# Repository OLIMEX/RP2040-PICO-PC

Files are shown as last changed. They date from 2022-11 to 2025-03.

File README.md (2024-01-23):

# RP2040-PICO-PC
Board of peripherals for Raspberry Pi RP2040-PICO which adds:

- HDMI/DVI 
- Audio 
- Micro SD card 
- Li-po charger 
- UEXT
- USB-OTG 

Allows to create a small PC with monitor and keyboard.

The RP2040-PICO-PC design is Open-Source Hardware (OSHW).

## Licenses

* Hardware is released under CERN Open Hardware Licence Version 2 - Strongly Reciprocal, all silkscreen credits to Olimex should remain;
* Software is released under GPL3 Licensee
* Documentation is released under CC BY-SA 4.0

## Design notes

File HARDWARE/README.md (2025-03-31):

RP2040-PICO-PC HARDWARE

This folder conaints design source files for each major hardware revisions.

There are also PDF exports of the schematic and BOM exports available.

The designs are made with KiCAD. Below you can find revision changes:

====

- Hardware revision D

1. Con2 changed to qwst1 and pinout changed!
2. Imropoved the pads and the soldering of all bigger components. They should now be more sturdy.

====

- Hardware revision C

1. Added diode D1 at the HDMI connector. R6 changed to 27k.
2. I2C1 fixed. SCL and SDA were swapped at the processor (3.3V).
3. Added needed resistors and capacitors and ferrite beads to SD_Card.
4. Board size increased.

====

- Hardware revision B

Initial release.

====

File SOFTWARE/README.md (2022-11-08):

Software examples for Olimex RP2040-PICO-PC and Raspberry Pi Pico

Folder "no-OS-FatFS-SD-SPI-RPi-Pico" contains SD card example, the project was adapted for RP2040-PICO-PC using this one:

https://github.com/carlk3/no-OS-FatFS-SD-SPI-RPi-Pico

Folder "PicoDVI" contains DVI example, the project is made after this one:

https://github.com/Wren6991/PicoDVI

Folder "pico-pwm-audio" contains audio examle, the project is based on this one:

https://github.com/rgrosset/pico-pwm-audio

Folder "Prebuilt-UF2" contains prebuilt binaries for each of the three projects.

The environment to build the projects was configured accordind to the getting-started-with-pico.pdf guide:

https://datasheets.raspberrypi.com/pico/getting-started-with-pico.pdf

If you don't want to bother with building just use the prebuilt UF2 files, connect the Raspberry Pi Pico to your computer using a micro-USB cable, making sure that you hold down the BOOTSEL button to force it into USB Mass Storage Mode. The board should automatically appear as a external drive. You can now drag-and-drop the UF2 binary onto the external drive.

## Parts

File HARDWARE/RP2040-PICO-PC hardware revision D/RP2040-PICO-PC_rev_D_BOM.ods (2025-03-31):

Qty | Designation | Package | Designator
2 | 100OHM/0402 | R_0402_5MIL_DWS | R17,R20
2 | 220OHM/0402 | R_0402_5MIL_DWS | R18,R19
9 | 270OHM/0402 | R_0402_5MIL_DWS | R7,R8,R9,R10,R11,R12,R13,R14,R25
1 | 1.5K/0402 | R_0402_5MIL_DWS | R1
2 | 1.8K/0603 | R_0603_5MIL_DWS | R16,R21
1 | 2K/0402 | R_0402_5MIL_DWS | R4
6 | 2.2K/0402 | R_0402_5MIL_DWS | R2,R3,R15,R26,R27,R28
2 | 10K/0402 | R_0402_5MIL_DWS | R24,R29
1 | 100K/0402 | R_0402_5MIL_DWS | R5
1 | 27K/0402 | R_0402_5MIL_DWS | R6
1 | RMAT(4x0603)100K/5% | RA1206_(4X0603)_4B8_xx | RM1
3 | 100nF/10V/20%/X5R/0402 | C_0402_5MIL_DWS | C4,C5,C6
1 | 1uF/10V/10%/X5R/0603 | C_0603_5MIL_DWS | C2
1 | 10uF/6.3V/0603 | C_0603_5MIL_DWS | C1
2 | 47uF/6.3V/20%/X5R/0805 | C_0805_5MIL_DWS | C7,C3
1 | 600OHM/2A/ UPZ2012E-601-2R0TF/0805 | L_0805_5MIL_DWS | L1
1 | 1N5819(S4 SOD-123) | SOD-123_1C-2A_KA | D1
1 | LED/RED/300 mCd/0603 | LED_0603_KA | LED1
2 | BSS138 | SOT23 | FET2,FET3
1 | WPM2015-3/TR | SOT23 | FET1
1 | BL4054B-42TPRN | SOT-23-5 | U1
1 | 74LVC125APW | 74LVC125A(TSSOP14-14_-SOT402-1) | U3
1 | 2X(PN1X20(F-D-1X20-LF)) | RP_Pico2040 | RP2040_PLATFORM1
1 | TFC-WPAPR-08-LF | TFC-WPAPR-08 | MICRO_SD1
1 | DW02S | LIPO_BAT_VERTICAL_DW02S | BAT_CON1
1 | BH10S(B-D-02x5-LF) | BH10S | UEXT1
1 | SH1.0-4P-180D | BM04B-SRSS-TB | QWST1
1 | HDMI-SWM-19 | HDMI-SWM-19_Paste | HDMI1
1 | MISB-SWMM-5B-LF | USB-MICRO_MISB-SWMM-5B_LF_Past | USB1
1 | 3.5mm/PJ-W47S-05D2-LF | PJ-W47S-05D2-LF_5PIN_V2_LongerPads | AUDIO_JACK_1
1 | HN1x3 | HN1x3 | DBG1
1 | TACTILE/YTS-A016-X | YTS-A016-X | RST1
1 | FSMD035-1206 (NANOSMDC035F-2) | FUSE-1206 | FUSE1
1 | open | SJ_1_SMALLER | 5V_ENABLE1
2 | NA/0402 | R_0402_5MIL_DWS | R22,R23

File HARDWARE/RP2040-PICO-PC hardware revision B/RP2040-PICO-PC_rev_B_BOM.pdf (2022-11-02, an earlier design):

RP2040-PICO-PC_rev_B | 04/26/2021
Qty | Designation | Package | Designator
2 | SMD RES 0402 100 OHM 5% | R_0402_5MIL_DWS | R17,R20
2 | SMD RES 0402 220 OHM 5% | R_0402_5MIL_DWS | R18,R19
9 | SMD RES 0402 270 OHM 5% | R_0402_5MIL_DWS | R7,R8,R9,R10,R11, R12,R13,R14,R25
1 | SMD RES 0402 1.5 K 5% | R_0402_5MIL_DWS | R1
2 | SMD RES 0603 1.8 K 5% | R_0603_5MIL_DWS | R16,R21
1 | SMD RES 0402 2 K 5% | R_0402_5MIL_DWS | R4
7 | SMD RES 0402 2.2 K 5% | R_0402_5MIL_DWS | R2,R3,R6,R15, R26,R27,R28
1 | SMD RES 0402 10 K 5% | R_0402_5MIL_DWS | R24
1 | SMD RES 0402 100 K 5% | R_0402_5MIL_DWS | R5
2 | NA/0402 | R_0402_5MIL_DWS | R22,R23
1 | SMD CAP 0603 1 UF 10V X5R | C_0603_5MIL_DWS | C2
1 | SMD CAP 0603 10 UF 6.3V | C_0603_5MIL_DWS | C1
2 | SMD CAP 0805 47 UF 6.3V 20% | C_0805_5MIL_DWS | C3,C7
1 | SMD IC 74LVC125APW | 74LVC125A (TSSOP14-14_leads-4.4mm_body_width-SOT402-1) | U3
1 | BH10S(B-D-02x5-LF) | BH10S | UEXT1
1 | SMD IC BL4054B-42TPRN | SOT-23-5 | U1
2 | SMD TR BSS138 | SOT23 | FET2,FET3
1 | CI0104P1VK0(PH-4A) | CL0104PV1K0 | CON2
1 | DW02S | LIPO_BAT_ VERTICAL_DW02S | BAT_CON1
1 | SMD FUSE FSMD035 | FUSE-1206 | FUSE1
1 | HDMI-SWM-19 | HDMI-SWM-19-TEST | HDMI1
1 | SMD CON TFC-WPAPR-08 | TFC-WPAPR-08 | MICRO_SD1
1 | HN1x3 | HN1x3 | DBG1
1 | PJ-W47S-05D2-LF_V2 | PJ-W47S-05D2-LF_5PIN_V2 | AUDIO_JACK_1
1 | HN 1X40 | HN 1X40 | U2
1 | SMD LED 0603 RED 300 mCd | LED_0603_KA | LED1
1 | TSW34-W16PR-220-LF/SIDE | SIDE_WTCM-TR(3x4) | RST1
1 | SMD CON MISB-SWMM-5B-LF | USB-MINI | USB1
1 | SMD TR WPM2015-3/TR | SOT23 | FET1

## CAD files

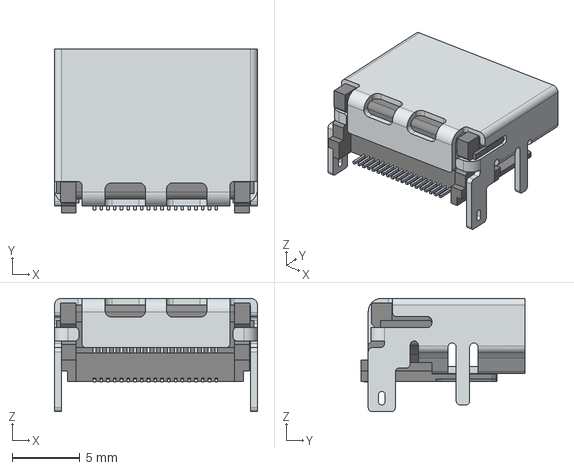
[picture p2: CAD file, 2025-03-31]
HARDWARE/RP2040-PICO-PC hardware revision D/3d/HDMI_19POS_SMD_Wurth_Electronic-685119134923.stp
15.0 x 12.2 x 8.38 mm

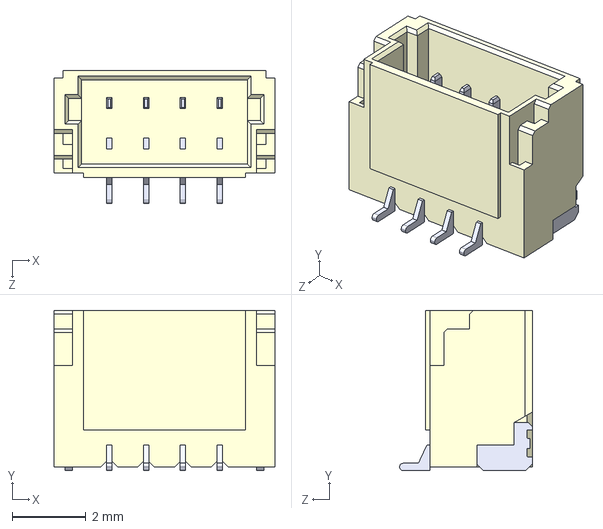
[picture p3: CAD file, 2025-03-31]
HARDWARE/RP2040-PICO-PC hardware revision D/3d/BM04B-SRSS-TB.STEP
6.00 x 4.35 x 3.60 mm

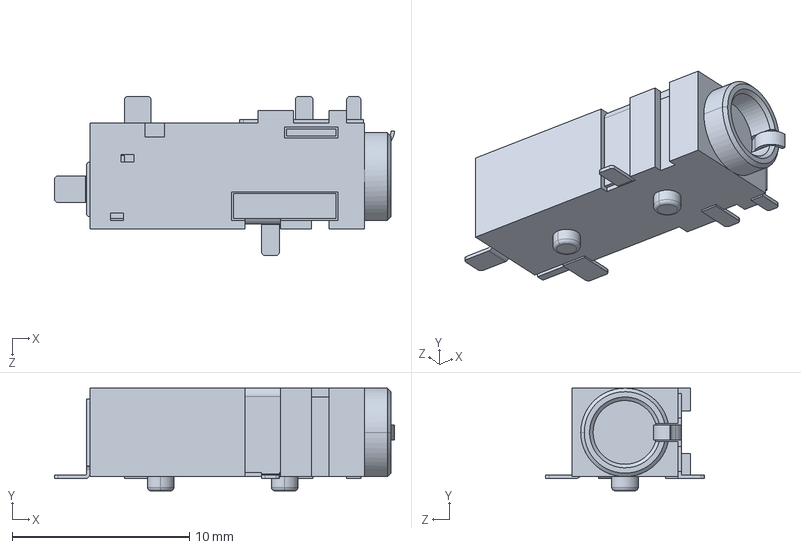
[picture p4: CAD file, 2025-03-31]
HARDWARE/RP2040-PICO-PC hardware revision D/3d/CUI_SJ-43515TS-SMT-TR.step
19.2 x 5.80 x 9.00 mm

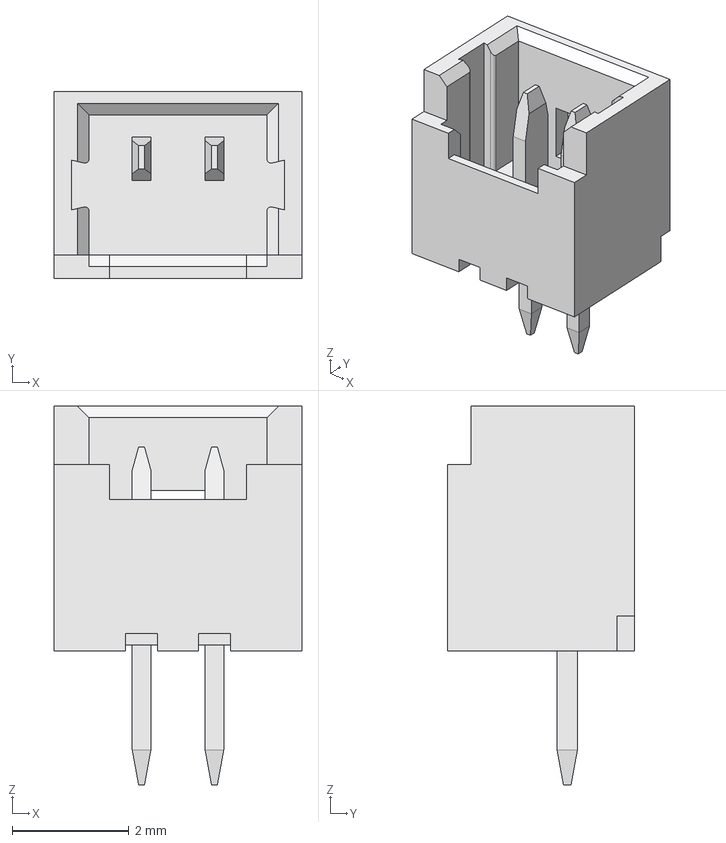
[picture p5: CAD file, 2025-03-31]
HARDWARE/RP2040-PICO-PC hardware revision D/3d/Molex_PicoBlade_530470210.step
4.25 x 3.20 x 6.50 mm

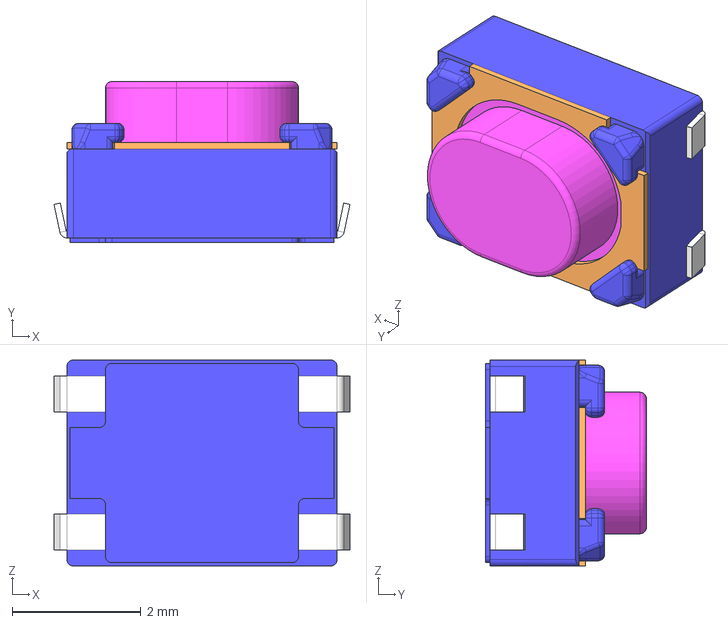
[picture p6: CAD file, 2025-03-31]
HARDWARE/RP2040-PICO-PC hardware revision D/3d/YTS-A016-X(SKRPABE010).stp
4.60 x 2.50 x 3.20 mm

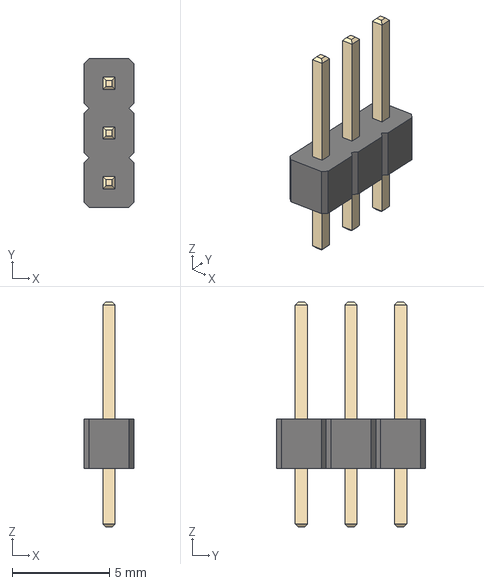
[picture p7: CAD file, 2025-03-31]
HARDWARE/RP2040-PICO-PC hardware revision D/3d/HN1x3-PinHeader_1x03_P2.54mm_Vertical.step
2.54 x 7.62 x 11.5 mm

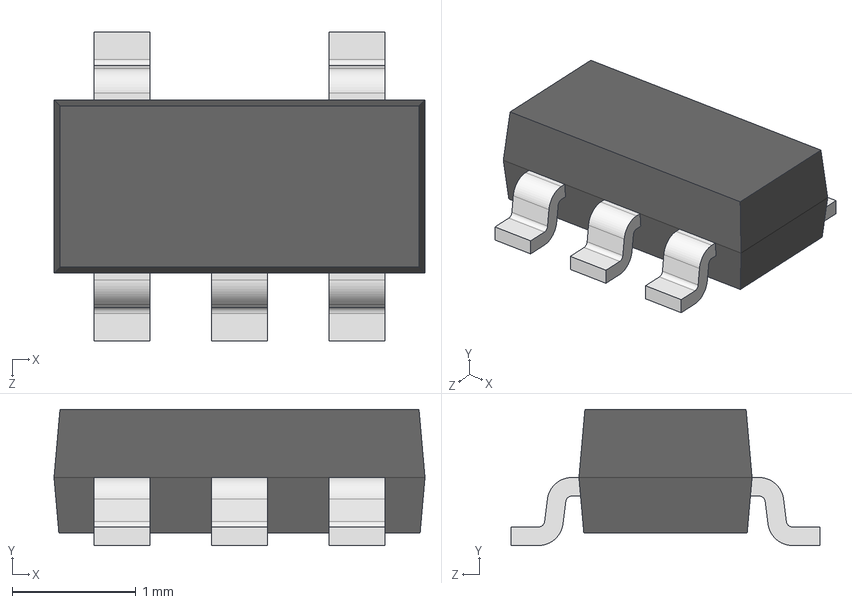
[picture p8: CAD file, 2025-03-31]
HARDWARE/RP2040-PICO-PC hardware revision D/3d/SOT-23-5.step
3.00 x 1.10 x 2.50 mm

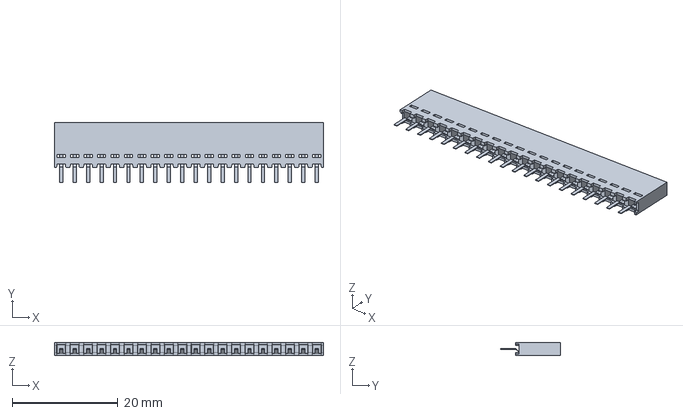
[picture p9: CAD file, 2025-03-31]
HARDWARE/RP2040-PICO-PC hardware revision D/3d/PN1x20-Molex_C-Grid_901471120_1x20_P2.54mm_Vertical.step
50.8 x 11.4 x 2.54 mm

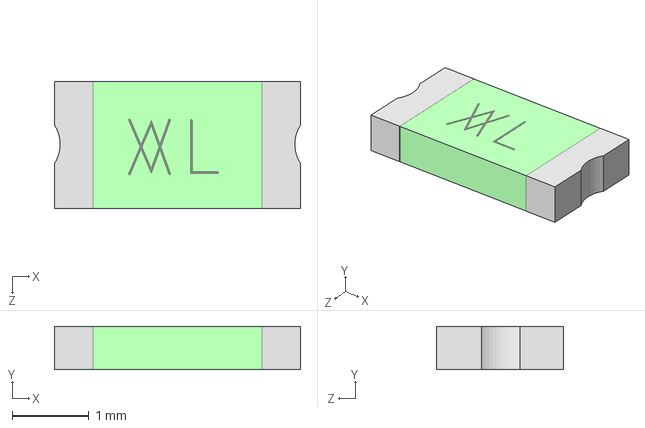
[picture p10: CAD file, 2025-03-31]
HARDWARE/RP2040-PICO-PC hardware revision D/3d/SMD075F.step
3.20 x 0.562 x 1.65 mm

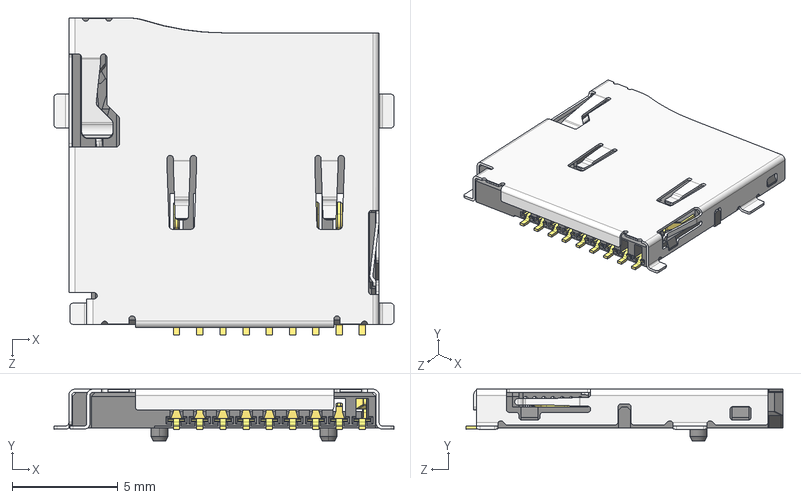
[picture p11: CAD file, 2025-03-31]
HARDWARE/RP2040-PICO-PC hardware revision D/3d/TFC-WPAPR-08---112J-TXAR-R_C_1-1.STEP
16.1 x 2.45 x 15.0 mm

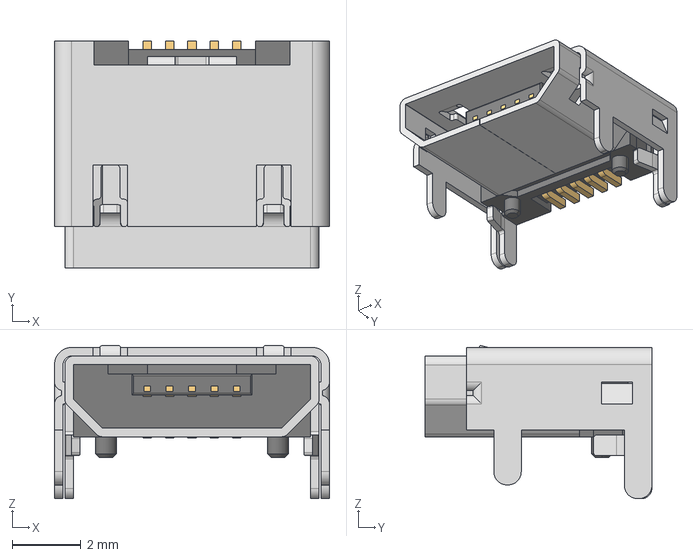
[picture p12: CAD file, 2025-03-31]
HARDWARE/RP2040-PICO-PC hardware revision D/3d/usb_micro_4p.stp
8.00 x 6.60 x 4.46 mm

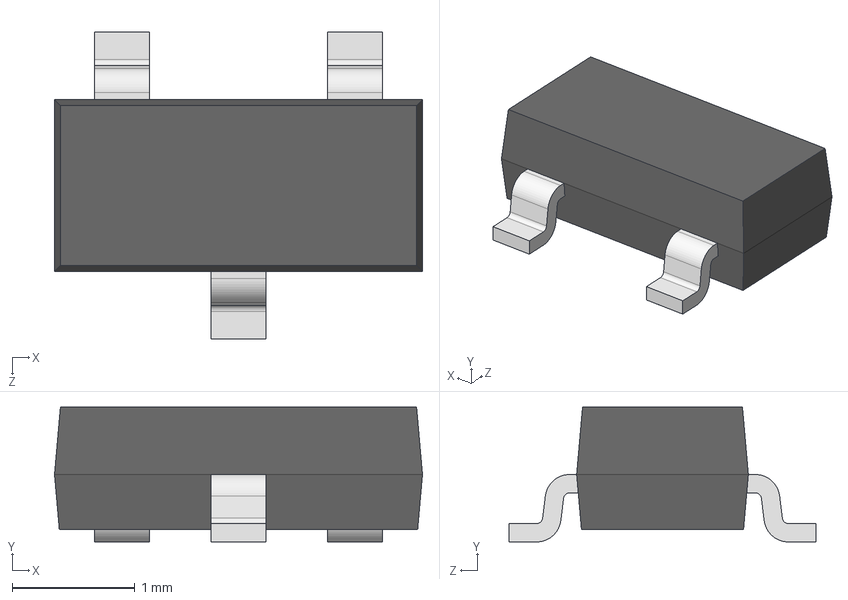
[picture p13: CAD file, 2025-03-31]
HARDWARE/RP2040-PICO-PC hardware revision D/3d/SOT-23.step
3.00 x 1.10 x 2.50 mm

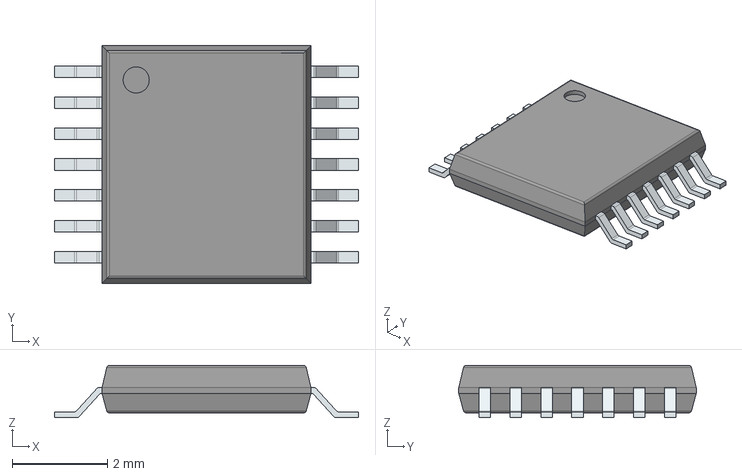
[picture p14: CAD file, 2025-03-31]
HARDWARE/RP2040-PICO-PC hardware revision D/3d/74LVC125APW,118.stp
6.40 x 5.00 x 1.10 mm
PinsArrayLR

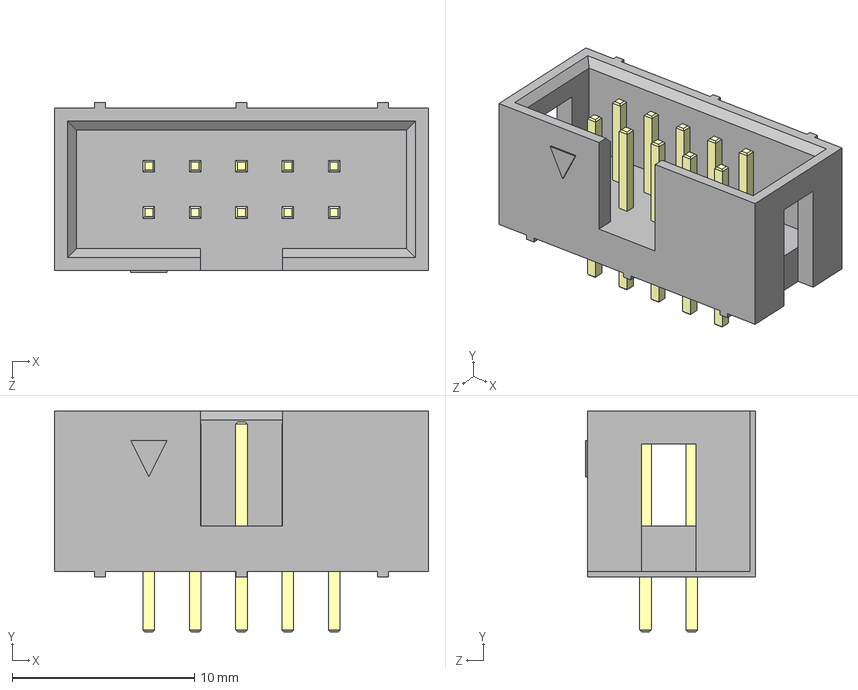
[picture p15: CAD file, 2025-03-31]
HARDWARE/RP2040-PICO-PC hardware revision D/3d/BH-10__64.step
20.5 x 12.1 x 9.30 mm

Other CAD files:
HARDWARE/RP2040-PICO-PC hardware revision D/3d/SOD123.step
HARDWARE/RP2040-PICO-PC hardware revision C/3d/CI0104P1VK0.STEP
HARDWARE/RP2040-PICO-PC hardware revision C/3d/SOD123.step

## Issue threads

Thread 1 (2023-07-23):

Use of PWM sound with DVI

ikjordan, 2023-07-23:
The supplied PicoDVI code uses PWM to generate the DVI clock on pins 12 and 13. The boards audio out is on pins 27 and 28.

Pin 28 and pin 12 are on the same PWM channel (6A), so it is not possible to configure different PWM clock frequencies for the two pins.
In effect this means that PWM stereo sound does not work with the supplied PicoDVI code.

A workaround is to generate the DVI clock via a very simple pio state machine. The PWM clock can then be configured for pin 28.

The PicoDVI library at:
https://github.com/ikjordan/PicoDVI
has been updated with these changes. I can raise a PR on this repo if you would like

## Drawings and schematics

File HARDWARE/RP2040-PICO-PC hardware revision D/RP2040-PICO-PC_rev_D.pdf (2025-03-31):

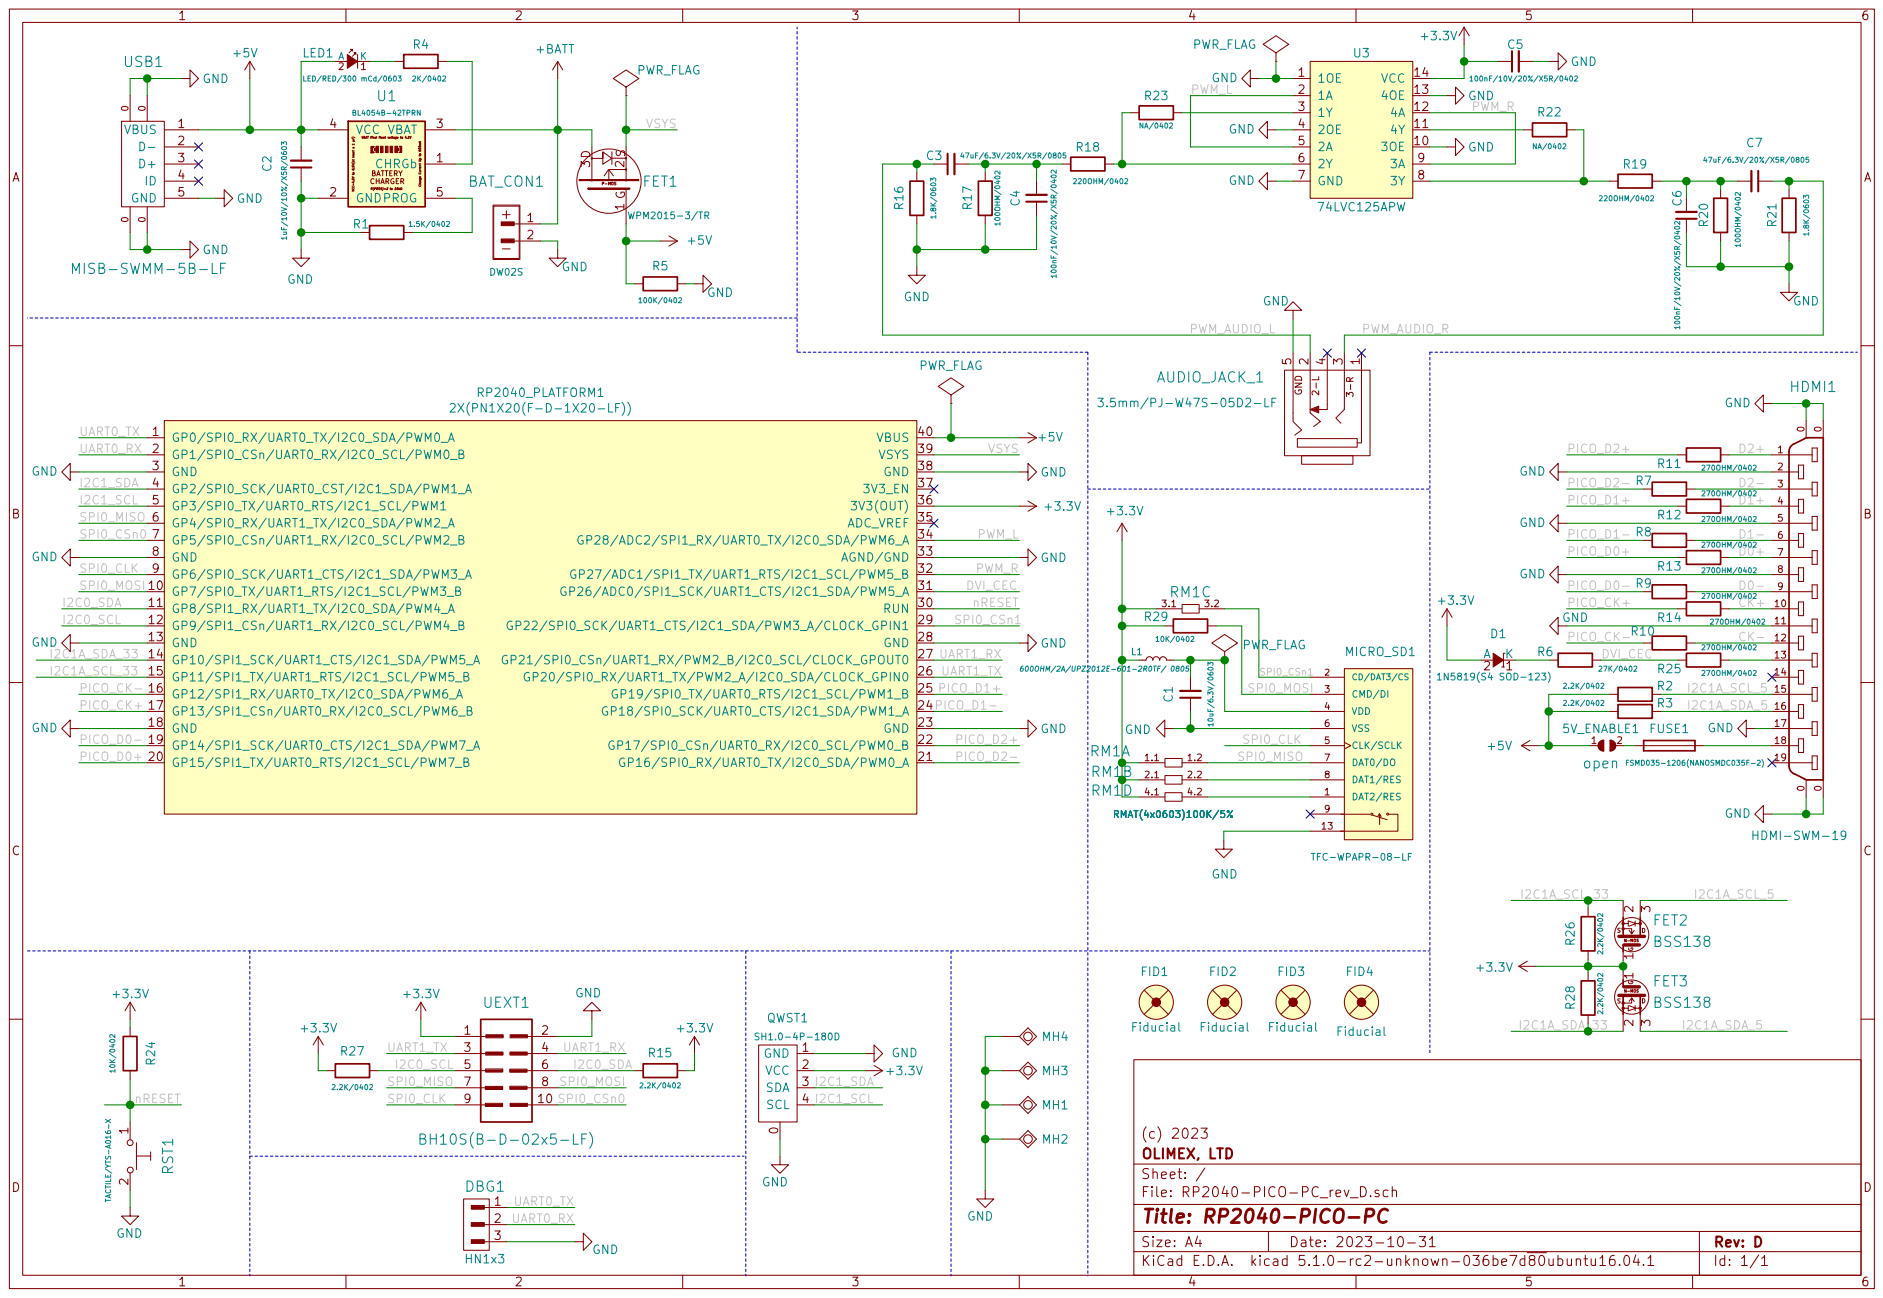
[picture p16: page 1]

LED/RED/300 mCd/0603 GND C2 1uF/10V/10%/X5R/0603 +5V

0 GND 1 VCC 2 SDA 3 SCL 4 QWST1

File: RP2040-PICO-PC_rev_D.sch Sheet: / OLIMEX, LTD

Id: 1/1 Title: RP2040-PICO-PC

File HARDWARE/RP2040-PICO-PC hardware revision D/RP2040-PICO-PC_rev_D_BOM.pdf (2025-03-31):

RP2040-PICO-PC_rev_D-BOM | 11/03/2023

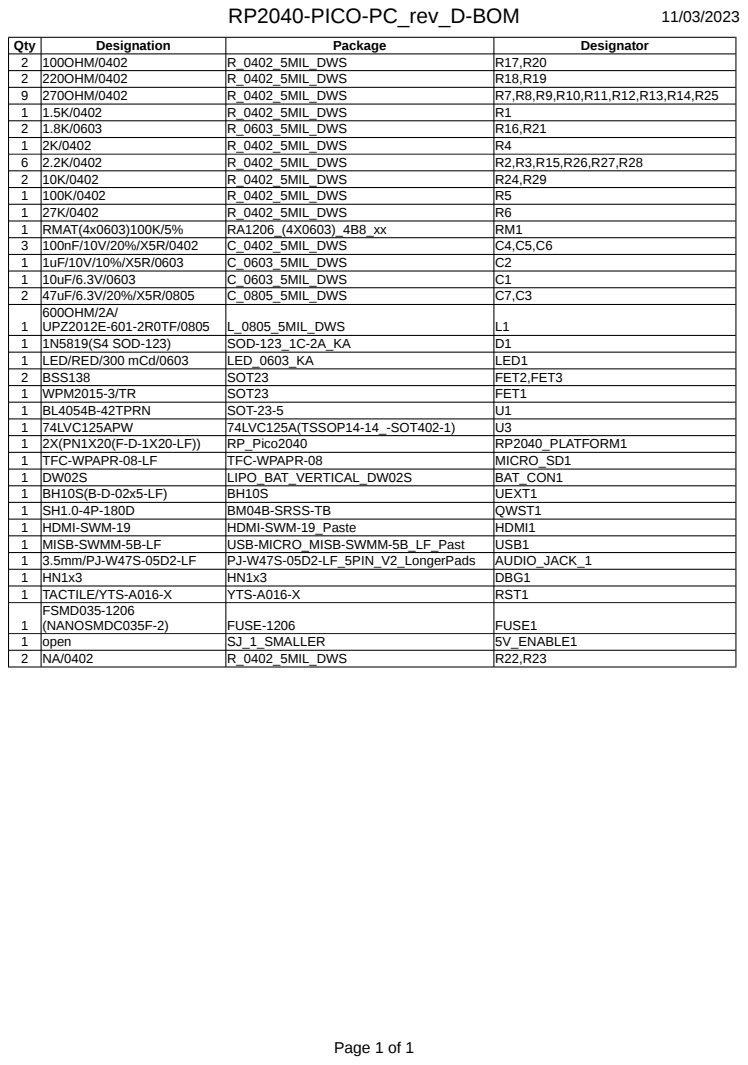
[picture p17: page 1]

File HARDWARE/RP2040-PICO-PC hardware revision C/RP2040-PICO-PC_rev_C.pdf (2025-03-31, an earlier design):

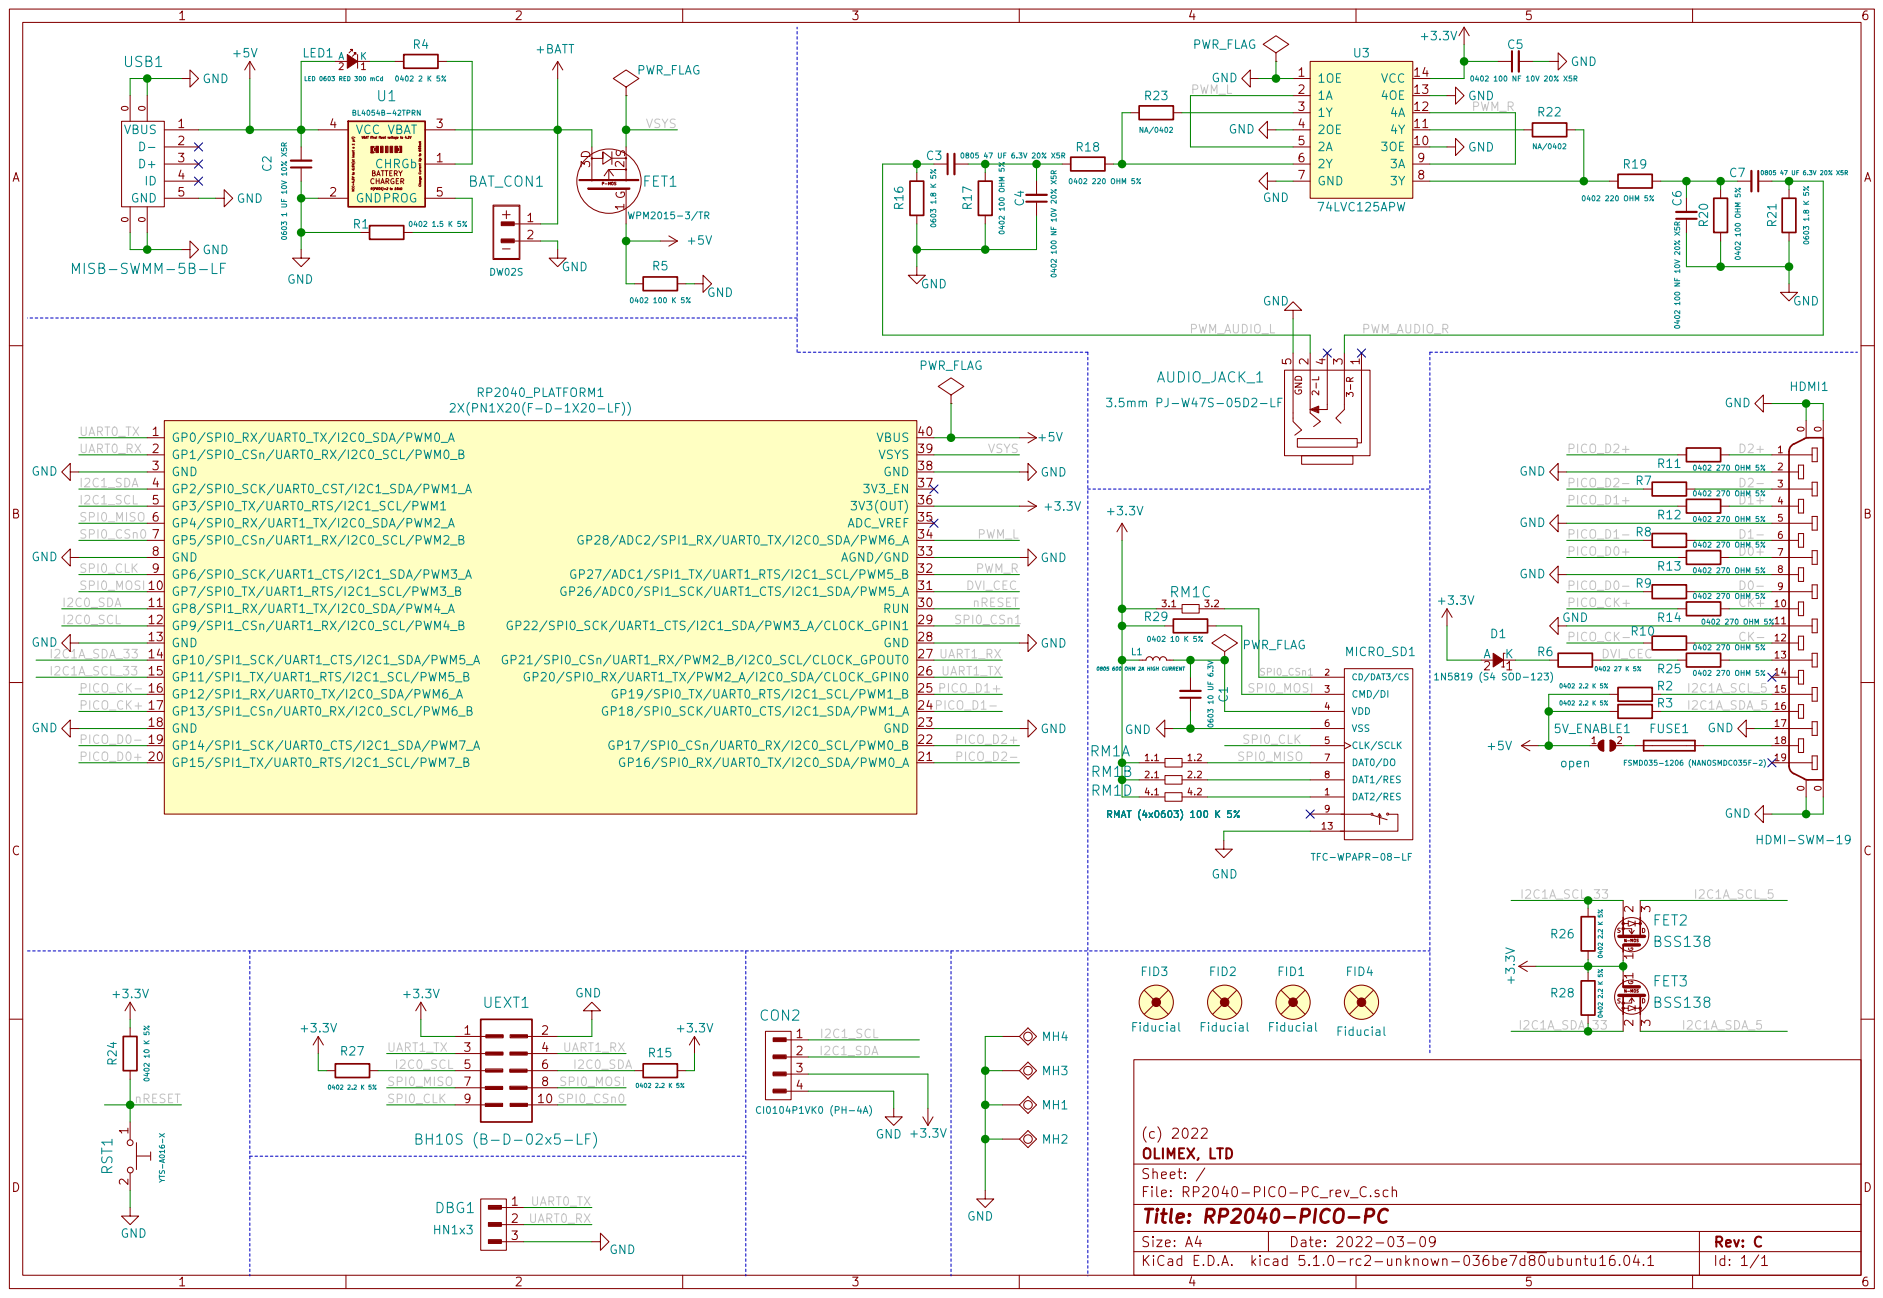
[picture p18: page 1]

LED 0603 RED 300 mCd GND C2 0603 1 UF 10V 10% X5R +5V

File: RP2040-PICO-PC_rev_C.sch Sheet: / OLIMEX, LTD

Id: 1/1 Title: RP2040-PICO-PC

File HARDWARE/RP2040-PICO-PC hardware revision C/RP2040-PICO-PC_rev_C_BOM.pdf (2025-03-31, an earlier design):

RP2040-PICO-PC_Rev_C_BOM | 03/10/2022

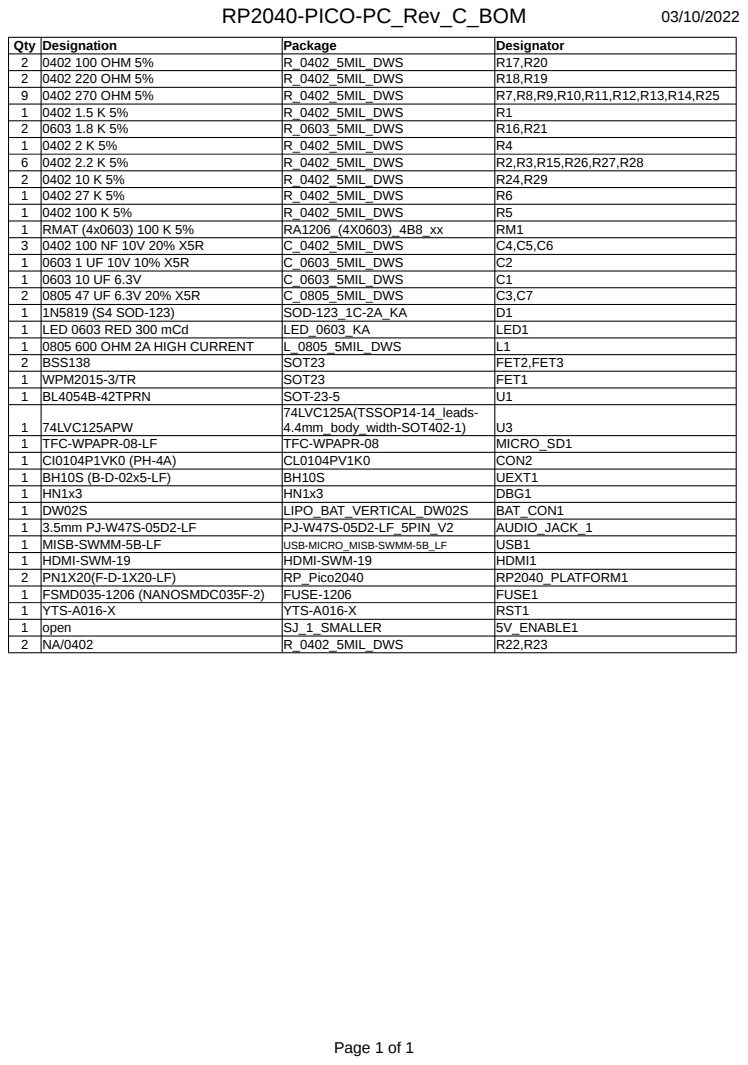
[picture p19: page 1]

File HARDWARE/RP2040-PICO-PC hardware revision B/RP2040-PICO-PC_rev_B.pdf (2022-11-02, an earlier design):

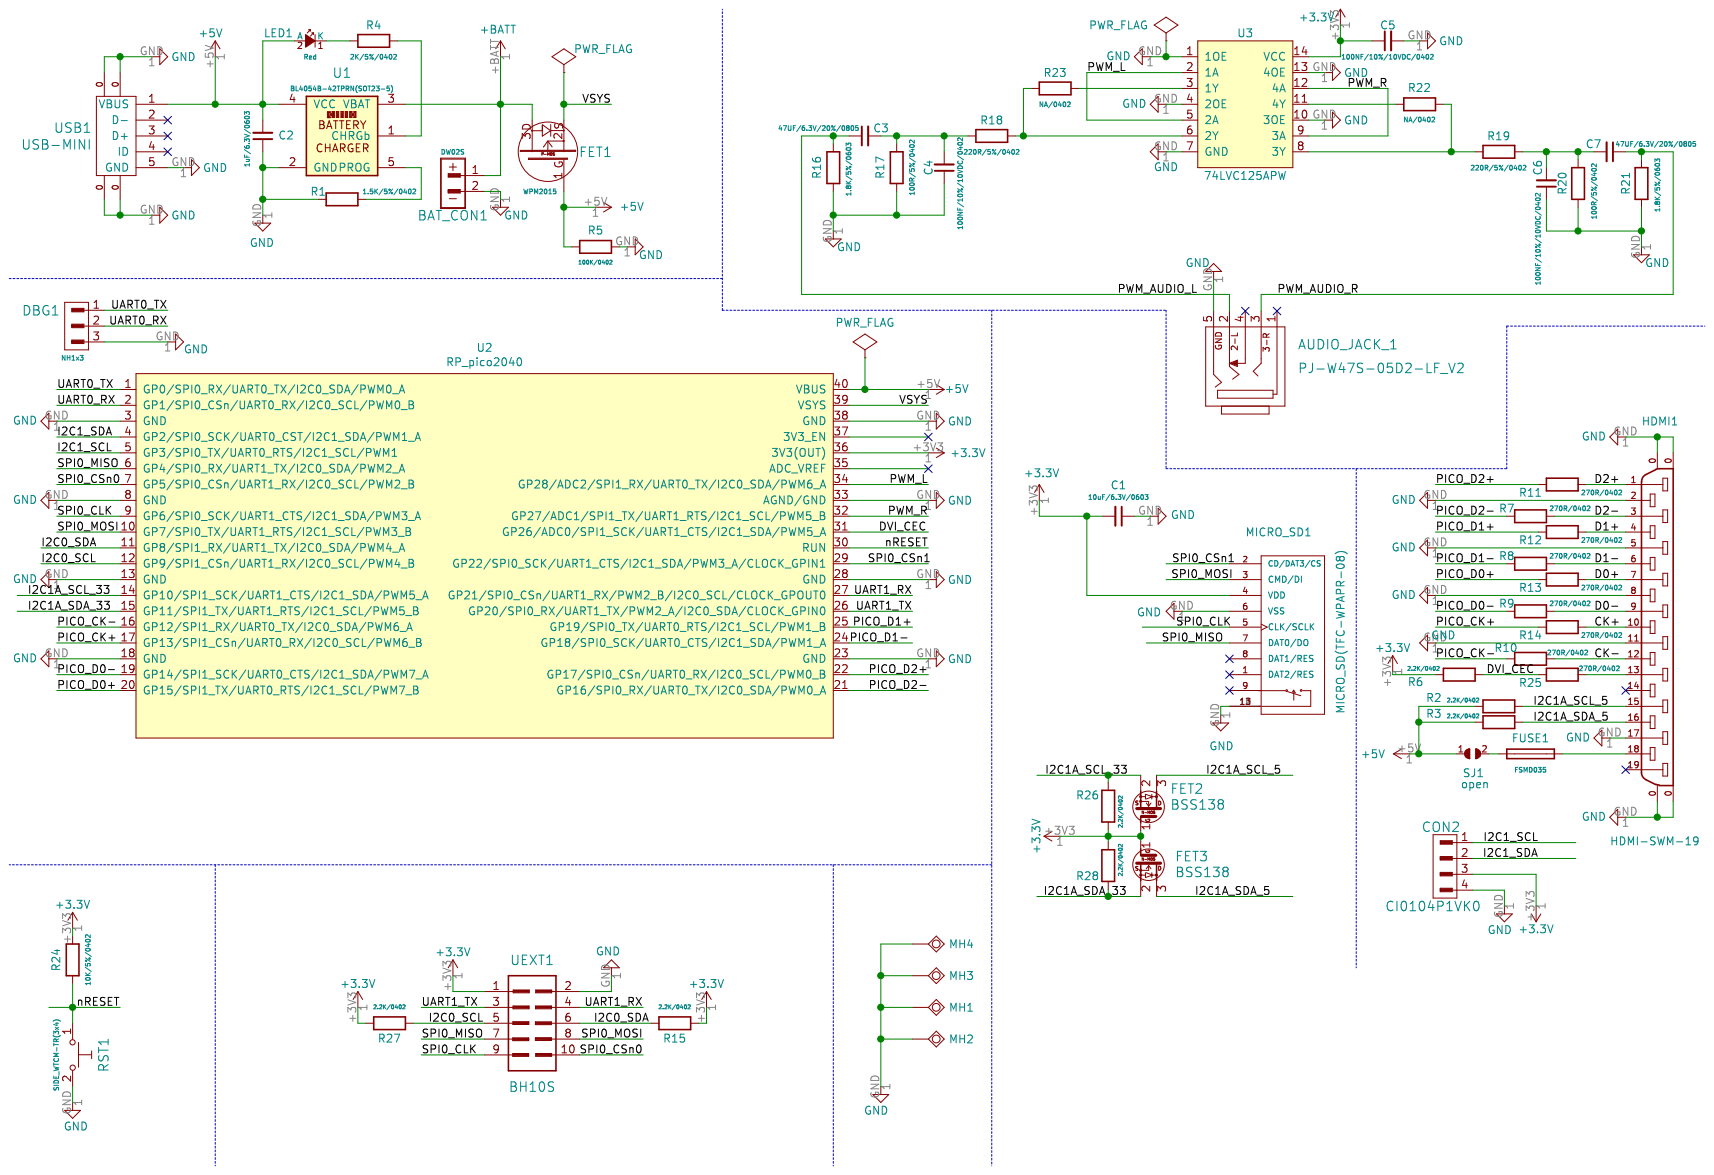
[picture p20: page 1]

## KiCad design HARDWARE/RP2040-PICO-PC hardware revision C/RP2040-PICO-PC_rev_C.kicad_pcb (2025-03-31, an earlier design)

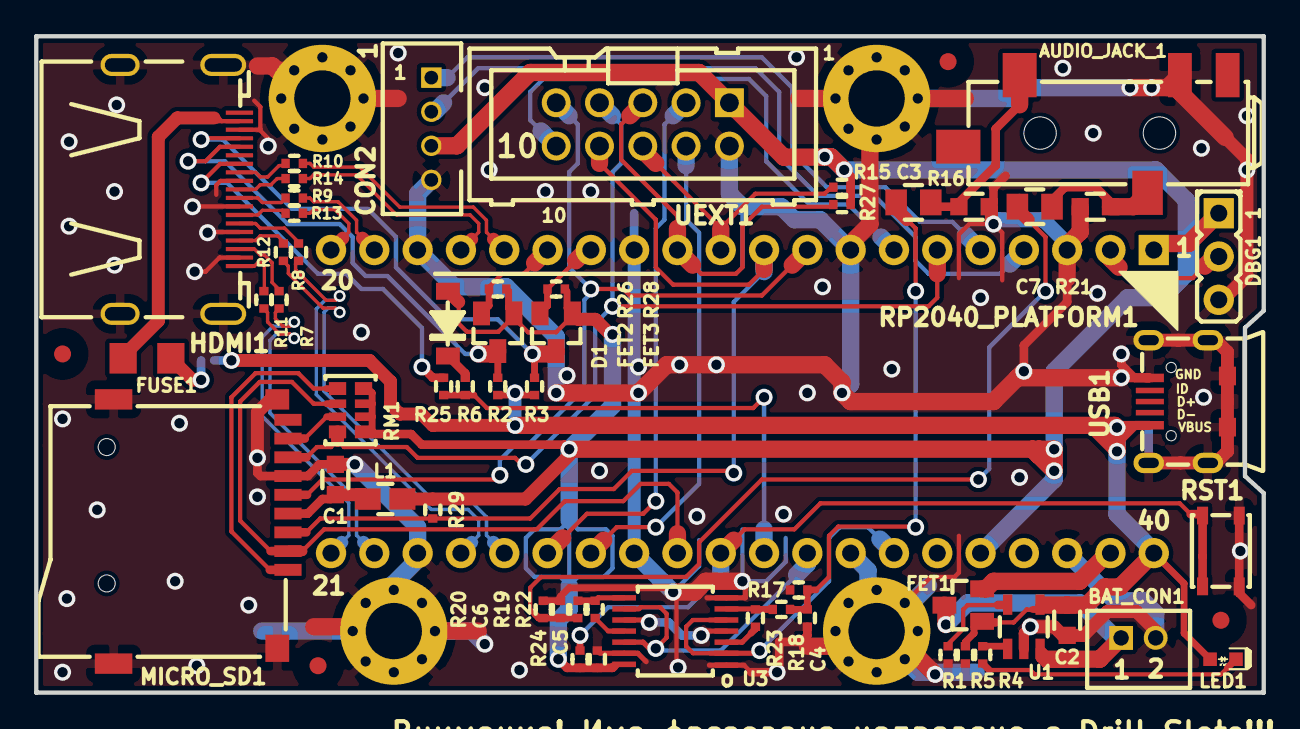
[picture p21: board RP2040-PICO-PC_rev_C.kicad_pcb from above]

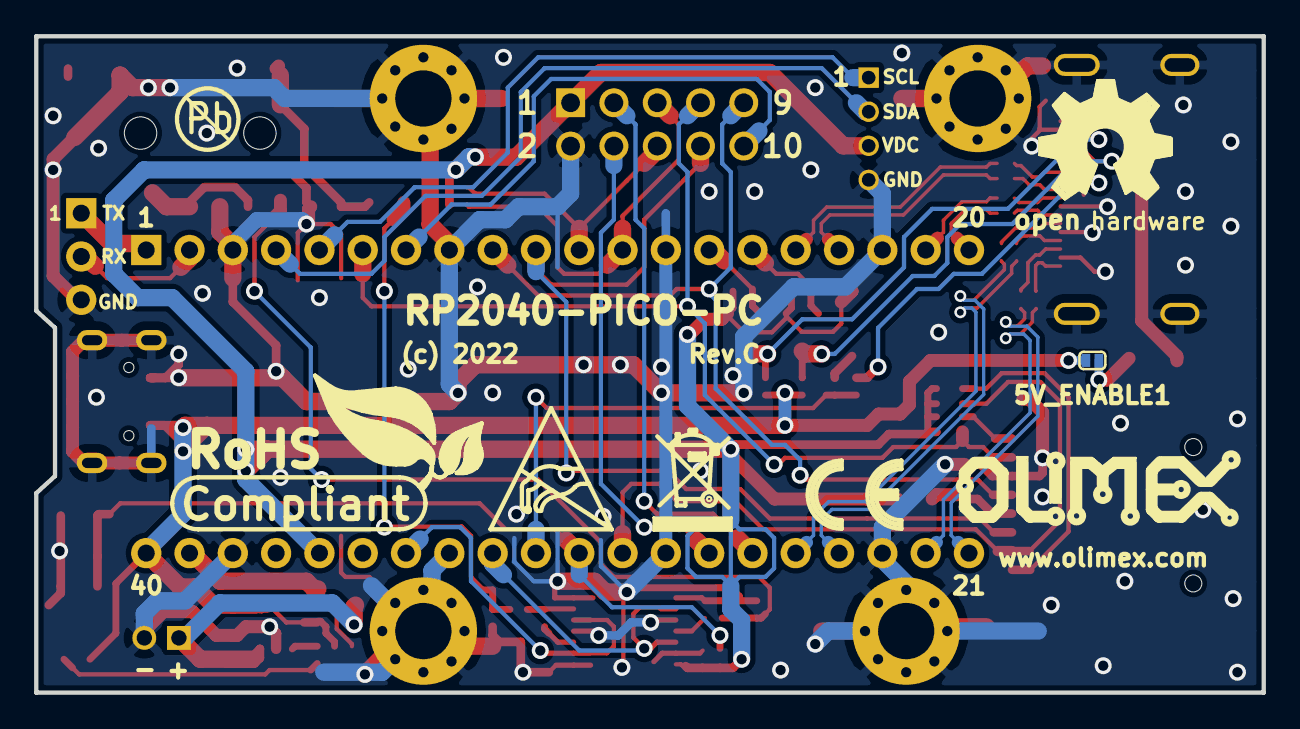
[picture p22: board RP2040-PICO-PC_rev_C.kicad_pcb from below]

Board: 2 copper layers, 72.0 x 38.5 mm, 71 parts (7 on the bottom side), 60 nets.

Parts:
5V_ENABLE1: open; SJ_1_SMALLER
AUDIO_JACK_1: 3.5mm PJ-W47S-05D2-LF; PJ-W47S-05D2-LF_5PIN_V2
Antistatic: Logo; LOGO_ANTISTATIC_1
BAT_CON1: DW02S; LIPO_BAT_VERTICAL_DW02S
C1: 0603 10 UF 6.3V; C_0603_5MIL_DWS
C2: 0603 1 UF 10V 10% X5R; C_0603_5MIL_DWS
C3, C7: 0805 47 UF 6.3V 20% X5R; C_0805_5MIL_DWS
C4, C5, C6: 0402 100 NF 10V 20% X5R; C_0402_5MIL_DWS
CON2: CI0104P1VK0 (PH-4A); CL0104PV1K0
D1: 1N5819 (S4 SOD-123); SOD-123_1C-2A_KA
DBG1: HN1x3
FET1: WPM2015-3/TR; SOT23
FET2, FET3: BSS138; SOT23
FID1, FID2, FID3, FID4: Fiducial; Fiducial1x3
FUSE1: FSMD035-1206 (NANOSMDC035F-2); FUSE-1206
HDMI1: HDMI-SWM-19
L1: 0805 600 OHM 2A HIGH CURRENT; L_0805_5MIL_DWS
LED1: LED 0603 RED 300 mCd; LED_0603_KA
MH1, MH2, MH3, MH4: Mounting_hole_Shield_3.3mm
MICRO_SD1: TFC-WPAPR-08-LF; TFC-WPAPR-08
OLIMEX_LOGO: Logo; OLIMEX_LOGO_TB
Open_Hardware: Logo; LOGO_OPENHARDWARE_8x8
PB_FREE: Logo; LOGO_PBFREE
R1: 0402 1.5 K 5%; R_0402_5MIL_DWS
R2, R3, R15, R26, R27, R28: 0402 2.2 K 5%; R_0402_5MIL_DWS
R4: 0402 2 K 5%; R_0402_5MIL_DWS
R5: 0402 100 K 5%; R_0402_5MIL_DWS
R6: 0402 27 K 5%; R_0402_5MIL_DWS
R7, R8, R9, R10, R11, R12, R13, R14, R25: 0402 270 OHM 5%; R_0402_5MIL_DWS
R16, R21: 0603 1.8 K 5%; R_0603_5MIL_DWS
R17, R20: 0402 100 OHM 5%; R_0402_5MIL_DWS
R18, R19: 0402 220 OHM 5%; R_0402_5MIL_DWS
R22, R23: NA/0402; R_0402_5MIL_DWS
R24, R29: 0402 10 K 5%; R_0402_5MIL_DWS
RM1: RMAT (4x0603) 100 K 5%; RA1206_(4X0603)_4B8_xx
RP2040_PLATFORM1: 2X(PN1X20(F-D-1X20-LF)); RP_Pico2040
RST1: YTS-A016-X
Recycle_bin: logo; LOGO_RECYCLEBIN_1
RoHS_Complaint: Logo; LOGO_ROHS_1
U1: BL4054B-42TPRN; SOT-23-5
U3: 74LVC125APW; 74LVC125A(TSSOP14-14_leads-4.4mm_body_width-SOT402-1)
UEXT1: BH10S (B-D-02x5-LF); BH10S
USB1: MISB-SWMM-5B-LF; USB-MICRO_MISB-SWMM-5B_LF

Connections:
+3V3: C5.1, CON2.3, D1.2, FET2.1, FET3.1, L1.1, R15.1, R24.1, R26.2, R27.2, R28.2, R29.2, RM1.1.1, RM1.2.1, RM1.3.1, RM1.4.1, RP2040_PLATFORM1.36, U3.14, UEXT1.1
+5V: 5V_ENABLE1.1, C2.2, FET1.1, LED1.2, R2.1, R3.1, R5.2, RP2040_PLATFORM1.40, U1.4, USB1.1
+BATT: BAT_CON1.1, FET1.3, U1.3
/CK+: HDMI1.10, R14.2
/CK-: HDMI1.12, R10.2
/D0+: HDMI1.7, R13.2
/D0-: HDMI1.9, R9.2
/D1+: HDMI1.4, R12.2
/D1-: HDMI1.6, R8.2
/D2+: HDMI1.1, R11.2
/D2-: HDMI1.3, R7.2
/DVI_CEC: R6.2, R25.1, RP2040_PLATFORM1.31
/I2C0_SCL: R27.1, RP2040_PLATFORM1.12, UEXT1.5
/I2C0_SDA: R15.2, RP2040_PLATFORM1.11, UEXT1.6
/I2C1A_SCL_5: FET2.3, HDMI1.15, R2.2
/I2C1A_SCL_33: FET2.2, R26.1, RP2040_PLATFORM1.15
/I2C1A_SDA_5: FET3.3, HDMI1.16, R3.2
/I2C1A_SDA_33: FET3.2, R28.1, RP2040_PLATFORM1.14
/I2C1_SCL: CON2.1, RP2040_PLATFORM1.5
/I2C1_SDA: CON2.2, RP2040_PLATFORM1.4
/PICO_CK+: R14.1, RP2040_PLATFORM1.17
/PICO_CK-: R10.1, RP2040_PLATFORM1.16
/PICO_D0+: R13.1, RP2040_PLATFORM1.20
/PICO_D0-: R9.1, RP2040_PLATFORM1.19
/PICO_D1+: R12.1, RP2040_PLATFORM1.25
/PICO_D1-: R8.1, RP2040_PLATFORM1.24
/PICO_D2+: R11.1, RP2040_PLATFORM1.22
/PICO_D2-: R7.1, RP2040_PLATFORM1.21
/PWM_AUDIO_L: AUDIO_JACK_1.2, C3.1, R16.2
/PWM_AUDIO_R: AUDIO_JACK_1.3, C7.1, R21.2
/PWM_L: RP2040_PLATFORM1.34, U3.2, U3.5
/PWM_R: RP2040_PLATFORM1.32, U3.9, U3.12
/SPI0_CLK: MICRO_SD1.5, RP2040_PLATFORM1.9, UEXT1.9
/SPI0_CSn0: RP2040_PLATFORM1.7, UEXT1.10
/SPI0_CSn1: MICRO_SD1.2, RM1.3.2, RP2040_PLATFORM1.29
/SPI0_MISO: MICRO_SD1.7, RM1.1.2, RP2040_PLATFORM1.6, UEXT1.7
/SPI0_MOSI: MICRO_SD1.3, R29.1, RP2040_PLATFORM1.10, UEXT1.8
/UART0_RX: DBG1.2, RP2040_PLATFORM1.2
/UART0_TX: DBG1.1, RP2040_PLATFORM1.1
/UART1_RX: RP2040_PLATFORM1.27, UEXT1.4
/UART1_TX: RP2040_PLATFORM1.26, UEXT1.3
/VSYS: FET1.2, RP2040_PLATFORM1.39
/nRESET: R24.2, RP2040_PLATFORM1.30, RST1.1
GND: AUDIO_JACK_1.5, BAT_CON1.2, C1.1, C2.1, C4.1, C5.2, C6.1, CON2.4, DBG1.3, HDMI1.0, HDMI1.2, HDMI1.5, HDMI1.8, HDMI1.11, HDMI1.17, MH1.GND1, MH2.GND1, MH3.GND1, MH4.GND1, MICRO_SD1.6, MICRO_SD1.10, MICRO_SD1.11, MICRO_SD1.12, MICRO_SD1.13, R1.2, R5.1, R16.1, R17.1, R20.1, R21.1, RP2040_PLATFORM1.3, RP2040_PLATFORM1.8, RP2040_PLATFORM1.13, RP2040_PLATFORM1.18, RP2040_PLATFORM1.23, RP2040_PLATFORM1.28, RP2040_PLATFORM1.33, RP2040_PLATFORM1.38, RST1.2, U1.2, U3.1, U3.4, U3.7, U3.10, U3.13, UEXT1.2, USB1.0, USB1.5
unnamed: 5V_ENABLE1.2, FUSE1.1
unnamed: C1.2, L1.2, MICRO_SD1.4
unnamed: C3.2, C4.2, R17.2, R18.1
unnamed: C6.2, C7.2, R19.1, R20.2
unnamed: D1.1, R6.1
unnamed: FUSE1.2, HDMI1.18
unnamed: HDMI1.13, R25.2
unnamed: LED1.1, R4.2
unnamed: MICRO_SD1.1, RM1.4.2
unnamed: MICRO_SD1.8, RM1.2.2
unnamed: R1.1, U1.5
unnamed: R4.1, U1.1
unnamed: R18.2, R23.1, U3.6
unnamed: R19.2, R22.1, U3.8
unnamed: R22.2, U3.11
unnamed: R23.2, U3.3

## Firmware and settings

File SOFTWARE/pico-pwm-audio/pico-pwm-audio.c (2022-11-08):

#include <stdio.h>
#include "pico/stdlib.h"   // stdlib 
#include "hardware/irq.h"  // interrupts
#include "hardware/pwm.h"  // pwm 
#include "hardware/sync.h" // wait for interrupt 
 
// Audio PIN is to match some of the design guide shields. 
#define AUDIO_PIN1 27  // you can change this to whatever you like
#define AUDIO_PIN2 28  // you can change this to whatever you like

/* 
 * This include brings in static arrays which contain audio samples. 
 * if you want to know how to make these please see the python code
 * for converting audio samples into static arrays. 
 */
#include "sample.h"
//#include "ring.h"
//#include "thats_cool.h"
int wav_position = 0;

/*
 * PWM Interrupt Handler which outputs PWM level and advances the 
 * current sample. 
 * 
 * We repeat the same value for 8 cycles this means sample rate etc
 * adjust by factor of 8   (this is what bitshifting <<3 is doing)
 * 
 */
void pwm_interrupt_handler() {
    pwm_clear_irq(pwm_gpio_to_slice_num(AUDIO_PIN1));    
    //pwm_clear_irq(pwm_gpio_to_slice_num(AUDIO_PIN2));    
    if (wav_position < (WAV_DATA_LENGTH<<3) - 1)
    { 
        // set pwm level 
        // allow the pwm value to repeat for 8 cycles this is >>3 
        pwm_set_gpio_level(AUDIO_PIN1, WAV_DATA[wav_position>>3]);  
        pwm_set_gpio_level(AUDIO_PIN2, WAV_DATA[wav_position>>3]);  
        wav_position++;
    }
    else
    {
        // reset to start
        wav_position = 0;
    }
}

int main(void) {
    /* Overclocking for fun but then also so the system clock is a 
     * multiple of typical audio sampling rates.
     */
    stdio_init_all();
    set_sys_clock_khz(176000, true); 
    gpio_set_function(AUDIO_PIN1, GPIO_FUNC_PWM);
    gpio_set_function(AUDIO_PIN2, GPIO_FUNC_PWM);

    int audio_pin_slice1 = pwm_gpio_to_slice_num(AUDIO_PIN1);
    int audio_pin_slice2 = pwm_gpio_to_slice_num(AUDIO_PIN2);

    // Setup PWM interrupt to fire when PWM cycle is complete
    pwm_clear_irq(audio_pin_slice1);
    //pwm_clear_irq(audio_pin_slice2);
    pwm_set_irq_enabled(audio_pin_slice1, true);
    //pwm_set_irq_enabled(audio_pin_slice2, true);
    // set the handle function above
    irq_set_exclusive_handler(PWM_IRQ_WRAP, pwm_interrupt_handler); 
    irq_set_enabled(PWM_IRQ_WRAP, true);

    // Setup PWM for audio output
    pwm_config config = pwm_get_default_config();
    /* Base clock 176,000,000 Hz divide by wrap 250 then the clock divider further divides
     * to set the interrupt rate. 
     * 
     * 11 KHz is fine for speech. Phone lines generally sample at 8 KHz
     * 
     * 
     * So clkdiv should be as follows for given sample rate
     *  8.0f for 11 KHz1
     *  4.0f for 22 KHz
     *  2.0f for 44 KHz etc
     */
    pwm_config_set_clkdiv(&config, 8.0f); 
    pwm_config_set_wrap(&config, 250); 
    pwm_init(audio_pin_slice1, &config, true);
    pwm_init(audio_pin_slice2, &config, true);

    pwm_set_gpio_level(AUDIO_PIN1, 0);
    pwm_set_gpio_level(AUDIO_PIN2, 0);

    while(1) {
        __wfi(); // Wait for Interrupt
    }
}

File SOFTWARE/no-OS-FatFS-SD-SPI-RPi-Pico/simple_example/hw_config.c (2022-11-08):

/* hw_config.c
Copyright 2021 Carl John Kugler III

Licensed under the Apache License, Version 2.0 (the License); you may not use 
this file except in compliance with the License. You may obtain a copy of the 
License at

   http://www.apache.org/licenses/LICENSE-2.0 
Unless required by applicable law or agreed to in writing, software distributed 
under the License is distributed on an AS IS BASIS, WITHOUT WARRANTIES OR 
CONDITIONS OF ANY KIND, either express or implied. See the License for the 
specific language governing permissions and limitations under the License.
*/
/*

This file should be tailored to match the hardware design.

There should be one element of the spi[] array for each hardware SPI used.

There should be one element of the sd_cards[] array for each SD card slot.
The name is should correspond to the FatFs "logical drive" identifier.
(See http://elm-chan.org/fsw/ff/doc/filename.html#vol)
The rest of the constants will depend on the type of
socket, which SPI it is driven by, and how it is wired.

*/

#include <string.h>
//
#include "my_debug.h"
//
#include "hw_config.h"
//
#include "ff.h" /* Obtains integer types */
//
#include "diskio.h" /* Declarations of disk functions */

void spi0_dma_isr();

// Hardware Configuration of SPI "objects"
// Note: multiple SD cards can be driven by one SPI if they use different slave
// selects.
static spi_t spis[] = {  // One for each SPI.
    {
        .hw_inst = spi0,  // SPI component
        .miso_gpio = 4,  // GPIO number (not pin number)
        .mosi_gpio = 7,
        .sck_gpio = 6,

        /* The choice of SD card matters! SanDisk runs at the highest speed. PNY
           can only mangage 5 MHz. Those are all I've tried. */
        //.baud_rate = 1000 * 1000,
        //.baud_rate = 12500 * 1000,  // The limitation here is SPI slew rate.
        .baud_rate = 25 * 1000 * 1000, // Actual frequency: 20833333. Has
        // worked for me with SanDisk.

        .dma_isr = spi0_dma_isr
    }
};

// Hardware Configuration of the SD Card "objects"
static sd_card_t sd_cards[] = {  // One for each SD card
    {
        .pcName = "0:",           // Name used to mount device
        .spi = &spis[0],          // Pointer to the SPI driving this card
        .ss_gpio = 22,             // The SPI slave select GPIO for this SD card     // SPP
        .set_drive_strength = true,
        .ss_gpio_drive_strength = GPIO_DRIVE_STRENGTH_2MA,
        //.use_card_detect = false,

        // State variables:
        .m_Status = STA_NOINIT
    }
};

void spi0_dma_isr() { spi_irq_handler(&spis[0]); }

/* ********************************************************************** */
size_t sd_get_num() { return count_of(sd_cards); }
sd_card_t *sd_get_by_num(size_t num) {
    if (num <= sd_get_num()) {
        return &sd_cards[num];
    } else {
        return NULL;
    }
}
size_t spi_get_num() { return count_of(spis); }
spi_t *spi_get_by_num(size_t num) {
    if (num <= sd_get_num()) {
        return &spis[num];
    } else {
        return NULL;
    }
}

/* [] END OF FILE */

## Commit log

2022-11-02 Update
    Added hardware
    [RP2040-PICO-PC_rev_B-B_Cu.gbr, RP2040-PICO-PC_rev_B-B_Mask.gbr, RP2040-PICO-PC_rev_B-B_Paste.gbr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]
2025-03-31 Update
    Revision C and D and revision changes
    [74LVC125APW,118.stp, BH-10__64.step, BM04B-SRSS-TB.STEP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]

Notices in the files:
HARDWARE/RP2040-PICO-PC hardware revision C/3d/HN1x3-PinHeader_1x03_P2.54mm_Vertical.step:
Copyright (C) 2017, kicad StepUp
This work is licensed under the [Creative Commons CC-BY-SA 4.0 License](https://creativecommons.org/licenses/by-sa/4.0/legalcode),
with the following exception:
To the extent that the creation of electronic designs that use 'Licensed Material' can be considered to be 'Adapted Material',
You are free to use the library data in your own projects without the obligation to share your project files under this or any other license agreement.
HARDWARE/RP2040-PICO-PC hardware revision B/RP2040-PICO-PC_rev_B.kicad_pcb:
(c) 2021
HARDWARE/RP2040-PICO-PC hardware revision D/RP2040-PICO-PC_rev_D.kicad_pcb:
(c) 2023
